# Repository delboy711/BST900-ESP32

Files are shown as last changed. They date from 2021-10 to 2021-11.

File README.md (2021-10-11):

# BST900-ESP32
ESP32 firmware to control BST900 Boost Converters remotely
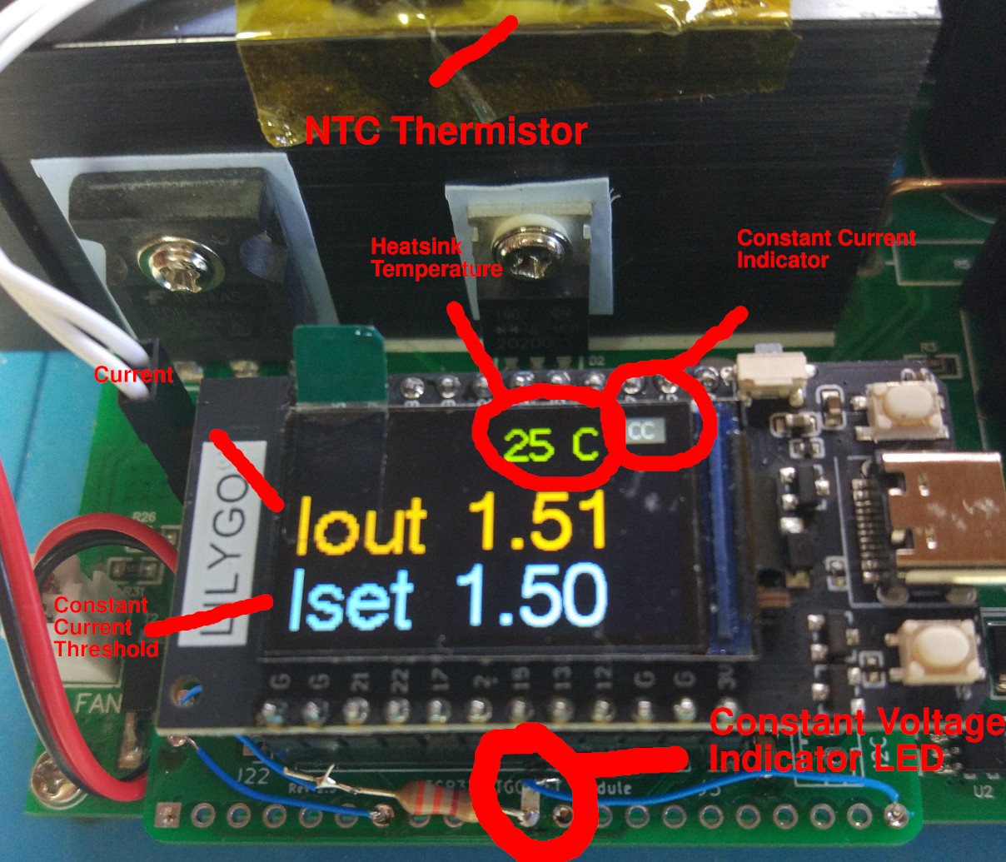
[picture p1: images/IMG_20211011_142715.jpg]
BST900-ESP32

[BST900](aliexpress.com/item/32838432319.html) boost converters are widely and cheaply available on AliExpress. They are sold under the brand name Ming-He among others, and there are also no-name clones available even cheaper.
They are claimed to operate up to 15A and 900W, but personally I would not operate them at that power without improvements to the cooling which I have detailed in my BST900 repository.

## Function
This firmware is offered as an evolution from [BST900](https://github.com/delboy711/BST900) which replaced the stock STM8 firmware and allowed control of a BST900 boost converter over a serial interface.

This new version replaces the BST900 daughter board with an ESP32 with or without an integrated TFT display and allows a BST900 
to be controlled remotely over a WiFi interface using MQTT, and for statistics to be gathered.
On power up the controller will revert to its saved state.

Local control is not currently supported. 

It has been designed to be used with a [TTGO T-Display board](aliexpress.com/item/33050667207.html), but is easily adapted for other display options (or none). An [ADS1115 ADC converter](aliexpress.com/item/32648046830.html) may optionally be used in preference to the onboard ESP32 ADC. The ADS1115 performs considerably better than the on board ADC in ESP32 and is highly recommended.
(All links to stores are examples only.)

In its initial version local control is not possible. If you are looking for a wider set of features, or for management of other types of converters check out 
[Drok-Juntek-on-steroids](https://github.com/rin67630/Drok-Juntek-on-steroids)

## Features

* Control over Voltage and Current over a wireless interface using MQTT.  Many variables may be controlled over MQTT including calibration.
* Statistics and alarms over MQTT
* Temperature measurement and alarms with an NTC thermistor attached to converter heatsink.
* Automatic fan control. Fan speed is proportional to either temperature or load current.
* Closed loop feedback to ensure output Voltage is accurate in Constant Voltage (CV) mode, and Output Current is accurate in Constant Current (CC) mode.
* Choice of display modes showing combinations of Input Voltage, Output Voltage, Output Current, Constant Current (CC) indication, and Temperature.
* Automatic shutdown on over temperature alarm, or on loss of communication with remote controller.
* Saving of all parameters in Flash memory. On power on, the controller will revert to this state.
* Over the Air software updates.

## Application
My home battery system is charged from AC mains. A BST900 Boost Converter is used to boost an AC to DC power supply output up to the battery voltage, and software
 running on NodeRed dynamically controls the constant current limit of the BST900 to match solar panel production to minimise export to the grid and save power for use later in the day.

## Compiling
This code compiles with PlatformIO IDE using the Arduino framework. Refer to the platformio.ini file for required libraries if using Arduino IDE.
Put your WIFI and MQTT credentials in the file include/credentials.h, and your MQTT server address and topic details in include/defines.h

## Usage
The BST900 will listen for commands on one MQTT topic, and send statistics every 30 seconds on another. By default it will time out and restart if no commands are 
received for two minutes. On power on it will send two messages giving its configuration and calibration settings.
Commands and statistics are JSON formatted like for example :-
```{"volts":45000,"amps":8000,"enable":true,"fan":0}```
Keywords may appear in any order. A list of keywords and their data types and ranges is in the file Keywords.md
If the keyword `"save":true` is given, all parameters are saved to flash memory and will be restored on power up.

## Hardware Connections
Connect the TTGO T-Display board to the ESP32 in the following way. BST900 pins are numbered from the top down.

|BST900 Left Socket | Signal Name  | TTGO Pin | ADS1115 Pin | Function |
| --- | --- | --- | --- | --- |
| Pin 1 | Iout Sense | GPIO 38 | Chan 1 | Current sense. Use either ADS115 or ESP32 pins | 
| Pin 2 | Vout Sense | GPIO 39 | Chan 2 | Voltage out sense. |
| Pin 3 | Vin Sense | GPIO 37 | Chan 0 | Voltage in sense. |
| Pin 4 | Iout PWM | GPIO 13 | | Constant Current threshold control |
| Pin 5 | Vout PWM | GPIO 15 | | Voltage out control |
| Pin 6 | Enable | GPIO 13 | | Converter Enable |
| Pin 7 | CV/CC Indicator | GPIO 27 | | Constant Voltage/Constant Current Indicator **Not** 3.3V safe|
| Pin 8 | Fan PWM | GPIO 2 | | Fan speed control |
| | SCL | GPIO 22 | SCL | I2C Clock |
| | SCD | GPIO 21 | SCD | I2C Data |
| | ADC Ref | GPIO 33 | +3.3V | Connect to 3.3V power rail. Used to compare with NTC temp reading |
| | Temp | GPIO 36 | | Connect up as +3.3V--10k resistor--GPIO 36--NTC Thermistor--GND |

Thermistor is [10K nominal at 25deg C Beta Coefficient=3950](https://lcsc.com/product-detail/NTC-Thermistors_Nanjing-Shiheng-Elec-MF52A103J3950-A1_C123378.html) or similar.
**Note:** Pin7 CV/VV is not 3.3V safe. At times 5V may appear on this pin. It must therefore be dropped down before the GPIO27 pin. A convenient method of dropdown is Pin7--3.3K resistor--GPIO27--Blue LED--GND
A blue LED will have ~2.5V forward voltage drop and will ensure a safe voltage appears on GPIO27. 
The LED will also serve as a visible indicator when the BST900 is in Constant Voltage mode.

If using ESP32 ADC connect 100nF capacitors from GPIO Pins 37, 38, and 39 to GND.

| BST900 Right Socket | Signal Name | TTGO Pin | ADS1115 Pin | Function |
| --- | --- | --- | --- | --- |
| Pin 1 | GND (Input)  | GND | GND | Ground | 
| Pin 2 | GND (Input)  | GND | GND | Ground |
| Pin 3 | GND (Output) | | | Do NOT CONNECT Connecting GNDs together disrupts Iout sense |
| Pin 4 | GND (Output) | | | Do NOT CONNECT Connecting GNDs together disrupts Iout sense |
| Pin 5 | +5V | +5V | | 5V Power rail  |
| Pin 6 | +5V | +5V | | 5V Power rail  |
| Pin 7 | | | | Tx pin (not used) |
| Pin 8 | | | | Rx pin (not used) |
| | | +3.3V | Vcc | ADS1115 power |

A 470 uF capacitor should be connected between +5V and GND as well as a 100nF capacitor.

A [circuit diagram](https://github.com/delboy711/BST900-ESP32/blob/main/hardware/BST900-ESP32/BST900-ESP32.pdf) of how to connect a TTGO T-Display to BST900 is in the hardware folder.

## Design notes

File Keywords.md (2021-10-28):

# MQTT Keywords
This is a list of the JSON keywords used in BST900-ESP32

## Command Keywords

| Keyword | Data Type | Range | Comment |
| :---: | :---: | :--- | :--- |
| amps | float | 1-15.0 | Constant current threshold in A |
| debug | boolean | true/false  | Puts extra debug data on serial interface |
| display | integer | 0 to 4 | Contents of TFT display. 0=blank, 1=Voltages, 2=Current, 3=Combined, 4=Cycle between 1 and 2 |
| enable | boolean | true/false  | Enable/disable boost conversion |
| factory | boolean | true/false  | Return to factory defaults and restart |
| fan | integer | 0-255 | Override auto fan speed. 0=auto Fan, 1-255=Fan speed |
| mqtt_timeout | integer | 20-65535 | Restart if no Mqtt commands seen in this many secs |
| overtemp_thresh | integer | 20-255 | Raise alarm and disable converter for 3 mins if this temperature is exceeded |
| restart | boolean | true/false  | Restart controller |
| save | boolean | true/false  | Save all parameters to Flash memory |
| volts | float | 8.0-120.0 | Output Voltage in V |

### Calibration Keywords

| Keyword | Data Type | Comment |
| :---: | :---: | :--- |
| vin_bias | float | Measured Vin bias offset. Normally zero |
| vin_res | float | Measured Vin units per mV |
| vout_bias | float | Measured Vout bias offset. Normally zero |
| vout_res | float | Measured Vout units per mV |
| iout_bias | float | Measured Iout bias offset. Normally zero |
| iout_res | float | Measured Iout units per mV |
| pwm_vout_bias | float | Vout offset. Normally zero |
| pwm_vout_step | float | Steps per mV |

## Response Keywords

| Keyword | Data Type | Range | Comment |
| :---: | :---: | :--- | :--- |
| bl_intensity | integer | 0-1023 | Backlight Intensity |
| display_mode | integer | 0-4 | Contents of TFT display. 0=blank, 1=Voltages, 2=Current, 3=Combined, 4=Cycle between 1 and 2 |
| enable | boolean | true/false  | Converter enable state |
| mqtt_timeout | integer | 20-65535 | Configyred MQTT Timeout |
| overtemp_thresh | integer | 20-255 | Configured over temperature threshold |
| reset_reason | integer | 1-16 | ESP32 [reset reason]( https://github.com/espressif/arduino-esp32/blob/master/libraries/ESP32/examples/ResetReason/ResetReason.ino) |
| targetIout | integer | 1-15000 | Configured Constant Current threshold in mA |
| targetVout | integer | 1-120000 | Configured Output Voltage in mV |
| Vin | integer | 1-120000 | Last measured Vin in mV|
| Vin_smoothed | integer | 1-120000 | Rolling average of Vin |
| Vout | integer | 1-120000 | Last measured Vout in mV|
| Vin_smoothed | integer | 1-120000 | Rolling average of Vout |
| Iout | integer | 1-15000 | Last measured Iout in mA|
| Iout_smoothed | integer | 1-15000 | Rolling average of Iout |
| fan | integer | 0-255 | Current fan voltage |
| overtemp | boolean | true/false  | Temperature alarm state |
| temperature | signedint | -127 to 127 | Current temperature |

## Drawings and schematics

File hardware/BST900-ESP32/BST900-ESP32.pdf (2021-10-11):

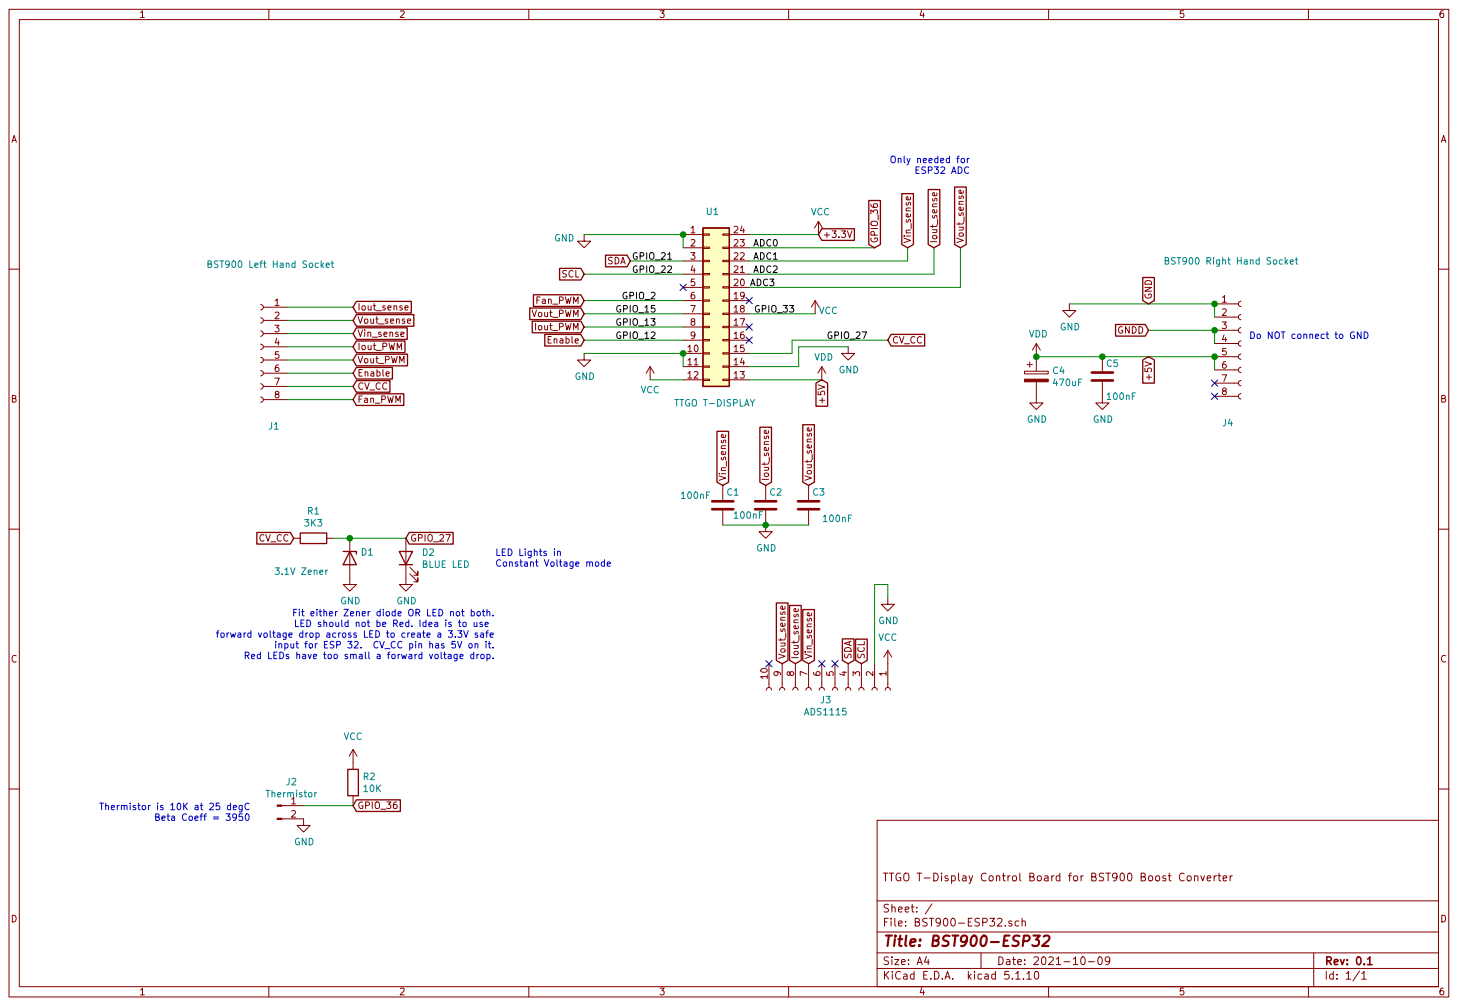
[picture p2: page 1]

Do NOT connect to GND

File: BST900-ESP32.sch Sheet: / TTGO T-Display Control Board for BST900 Boost Converter D2BLUE LED

Fit either Zener diode OR LED not both. LED should not be Red. Idea is to use

forward voltage drop across LED to create a 3.3V safe

input for ESP 32. CV_CC pin has 5V on it.
Red LEDs have too small a forward voltage drop.

Thermistor is 10K at 25 degC

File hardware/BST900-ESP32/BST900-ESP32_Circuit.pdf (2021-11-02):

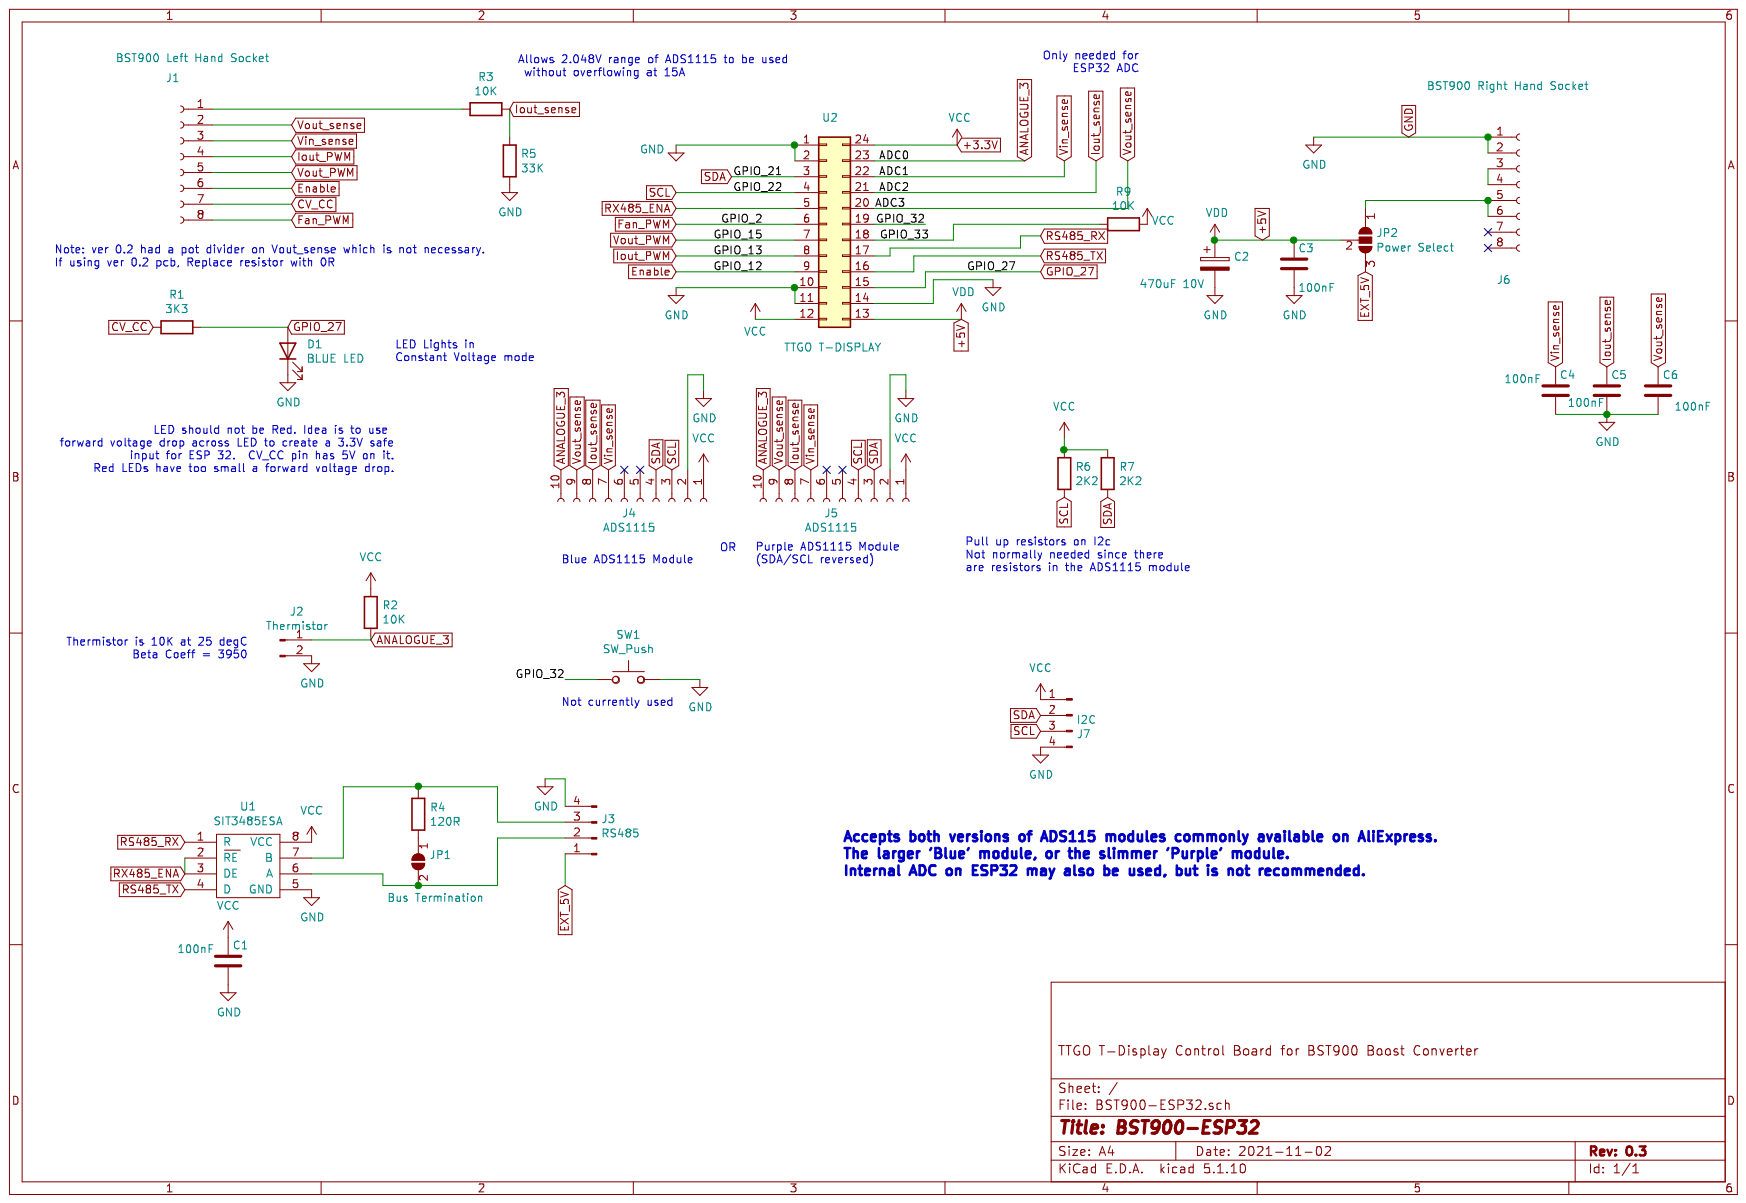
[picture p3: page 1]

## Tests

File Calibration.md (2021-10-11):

# Calibration
The default calibration should be fairly accurate, but if you find you need to recalibrate use this procedure.
Calibration of BST900-ESP32 is relatively easy. Equipment required is a multimeter, and a dummy resistive load
 such as an incandescent light bulb. Also required is a computer running an MQTT server such as [mosquitto](https://mosquitto.org/)
 with a text based MQTT client so commands can be sent to the BST900.
 
 To start calibrating first ensure the BST900 is connected to WiFi. On power on the BST900 will display its IP address on the TFT
  screen for a few seconds. If you do not see this ensure the code has been compiled with the correct credentials in the file 
  inc/credentials.h. Also ensure that credentials.h contains the correct credentials for your MQTT server, and that inc/defines.h contains 
  the IP address of your MQTT server. By default BST900 will subscribe to the topic 'bst900' to receive commands, and will send
   statistics every 30 seconds on the topic 'emon/bst900'.  Be aware that by default BST900 will expect to see a command at least every 
    two minutes on the 'bst900' topic or else it will declare a communication alarm and restart itself. This timeout period can 
    be adjusted by sending a JSON formatted MQTT command in the format.
    ```{"mqtt_timeout":600}```
If using mosquitto as an MQTT client the command would look like this:-
```mosquitto_pub  -u 'mqttuser' -P 'mqttpassword' -t 'bst900' -m '{"mqtt_timeout":600}'```

## Calibrating Voltage readings
 With a stable power supply of at least 9V connected to the BST900, and the output terminals of the BST900
  left open circuit open a terminal window and subscribe to the topic BST900 is sending statistics on.
  ```mosquitto_sub -v -u 'mqttuser' -P 'mqttpassword' -t 'emon/bst900'```
  On power up BST900 will send two messages giving the [reset reason](https://github.com/espressif/arduino-esp32/blob/master/libraries/ESP32/examples/ResetReason/ResetReason.ino), setup parameters, and 
  the calibration parameters. All these parameters can be configured with MQTT commands.

### Calibrating Measuring Input Voltage
  With a multimeter attached to the input terminals compare the measered voltage with the reported Voltage 'Vin' in the statistics report.
  Adjust the parameter 'vin_res' until the reported Voltage matches the measured using MQTT commands in the format.
  ```mosquitto_pub  -u 'mqttuser' -P 'mqttpassword' -t 'bst900' -m '{"vin_res":34.335}'```
  Now repeat the procedure using a much higher input voltage.
  Note: If you cannot find a value for 'vin_res' which works across all voltage ranges it is possible (but not likely) that adjusting the 
  parameter 'vin_bias' may help.
  
### Calibrating Measuring Output Voltage
  Now move the multmeter to the output terminals of the BST900. By definition the input voltage of a boost converter will appear on the output terminals even when it is not enabled.
  Repeat the previous procedure this time adjusting the parameter 'vout_res'.
  
### Calibrating Measuring Output Current
  Next with output terminals still open circuit look at the reported statistic for Iout and adjust the parameter 'iout_bias' until the reported current is zero.
  Now attach your dummy load to the output terminals. With your multimeter measure the current flowing in the dummy load.
  Compare with the reported value of Iout and adjust the parameter 'iout_res' until they match.  Repeat with another dummy load drawing a different current.

### Calibrating Output Voltage
  Calibration of output Voltage is semi automatic. So long as the parameter 'pwm_vout_step' is roughly accurate, then the BST900 will
   automatically adjust the output voltage until the measured output voltage matches the target voltage. If you find the output voltage
    is not accurate it may be adjusted by the parameter 'pwm_vout_step'. (Make small changes only).
    
  To set output voltages use the command:-
  ```mosquitto_pub  -u 'mqttuser' -P 'mqttpassword' -t 'bst900' -m '{"volts":3500, "enable":true}'```
  Note: Voltage is expressed in milliVolts, and current is expressed in milliAmps as integer numbers. Enable is a boolean and is either 
  'true' or 'false'.
  Note: Changes to 'pwm_vout_step' will not take effect unless the output voltage is also changed.
  Note: Output voltage will drop if the converter is in 'constant current' mode. Ensure the constant current threshold is high enough when
   calibrating output voltage.
  
### Calibrating Output Constant Current Threshold.
  Calibration of the constant current threshold is fully automatic.
  So long as the measured Iout is accurate then the constant current threshold should also be accurate.
  The command to set a constant current threshold would look like :-
  
  ```mosquitto_pub  -u 'mqttuser' -P 'mqttpassword' -t 'bst900' -m '{"volts":3500, "amps":1200 "enable":true}'```

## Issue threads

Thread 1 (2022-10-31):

BST 900 original firmware  i d like to contribute.

ouinouin, 2022-10-31:
Hi, sorry to bother you on here this project, i m actually just starting to use your "original" BST 900 firmware  in a solar powered environment.
unfortunately there is no "issue" button on the original BST 900 firmware

i prefered the BST900 firmware since it looks easy to manipulate everything i need with the serial port (i can connect an esp32 through the serial port directly and dont need hardware change. ( a great thing would be to be able to get some tasmota interaction on ESP32 :-) .

for now i m noticing while playing with the voltage that the protocol.md might be wrong :

Voltage Set

    Send: "VOLTAGE XXXXX"
    Receive: "VOLTAGE - OK" or "OK"

Set the maximum voltage level in mV.
Use the "CONFIG" command to confirm.

tell me if you re motivated to open the "issue" tab on the bst 900 if i can give feedback (on docs most likely, i m not really a coder).

PS : my project is to connect the input of BST 900 on the 48V DC of my solar powered system, and to dump the extra load in one resistance of my water heater, with a retroaction loop : trying to adapt the dump load dynamically based consumption information received from the solar panel production system, letting some predefined amount flowing in the battery for example, and adapting to the power curve of the sun during the day (i did the same in AC with thyristors, but its highly power inefficient, and i like the idea of doing DC only.
with some other solar enthusiasts, we have plenty of other projects that could take benefit of your great efforts.

delboy711, 2022-11-01:
Hi
Thanks for taking an interest in my project. I have taken a look at the github settings, but because the original BST900 STM8 based project is a fork of another project github does not permit the 'Issues' Tab to be enabled. Feel free to highlight any issues relating to it here.

Now as for the documentation for setting the voltage I have taken a look through the code and it looks to me as if voltage is declared in milliVolts on the serial interface but internally it is converted to centiVolts (because BST900 can have output voltages exceeding 65535mV which would overflow a 16 bit integer)

However it is a long time since I have worked on this code, and I no longer use this version myself so I could be wrong.

Have you got the code working yet? The biggest difficulty with this project is the fact that once you overwrite the stock firmware on the top board there is no way to go back to stock firmware again.

Now regarding your application be aware that a Boost converter like BST900 can raise the output voltage above the input voltage, and can control the current while doing so, but it cannot prevent the input voltage appearing on the output terminals even when disabled.  If you look at the basic circuit diagram of a boost converter you will see the input connects directly to the coil, through a diode to the output terminals. So if you have 48V going in, then the output will always be at least 48V and current can only be controlled when the output is higher than 48V.

I do actually have another project to do a similar function to your application which I use to dump excess solar power into a storage heater.  It uses an esp8266 to switch a Triac on for  complete AC cycles.  It is more efficient than a Thyristor, and does not produce any emf noise.  I have not uploaded this project to Github but if you are interested I could do so.

regards  Derek

ouinouin, 2022-11-02:
@delboy711  thanks for your constructive answer,  well noted for the issue propagation mode of github.
as you said, i could not turn on or off the output of the supply as expected since there is always at least the input voltage on the output.
the code works, i could in a test regulate voltage and current, this rocks. just the buttons seems not working but i dont know if its because i once misconnected the board upside down or because of some code (and i dont need the buttons indeed).

as a note for people interrested in doing the modding, I had to unsolder the 20 pins microcontroller on the board and put a real STM8 from a dev board inplace by unsoldering with hot air becuase i couldnt flash in situ
then I soldered back on the eval board the chinese component, and i still couldnt flash it : meaning, they dont ship this kind of supplies anymore with stm8. but this might be one pin compatible, so frankensteinisation si still doable.

for info , with this boost the goal can also be to supply some loads wich have 110/220AC adapters but in fact have a rectifier (like laptop supplies, led supplies etc etc. i did some interresting tests, some old dell laptop supplies are working directly with the 120V DC ,some led bulbs also works. this could make a lot of sense for a whole DC house transition.

another info : at 52V (which is the average voltage of my dc circuit , I can get a maximum of 300W of power @120V DC output.
I d like to trace the full curve of this unit since they state 15 ampx max and 120V max but there is nowhere a real set of curves of the unit and his efficiency (while doing my next session around this unit in 4 5 weeks, i ll try to caracterize this.

I dlike to have a DC boost unit capable of going from 50V zone to 220 V DC around 1KW ... to be able to try a maximum of devices and make a list of thigs that coud transition direct from ac to DC.  IF you know some macgic chinese stuff able to do this.

for your triac project, yes  id be interrested in seing what you did with a triac, to sse how you could manage to not have the full power during one period.

I have another project in parallel to regulate a dump load with an autotransformer that I would drive with a stepper motor. (nothing ne under the sun , already some projects are there n the internet, just the purpose to regulate and do a dump load is a bit new.)

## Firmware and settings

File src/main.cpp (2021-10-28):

/****************************************
 * BST900-ESP32
 * ESP32 firmware for BST900 BoostConverters
 * 
 * Oct '21
 * Derek Jennings
 * 
 * ****************************************/


#include <Arduino.h>
#include <WiFi.h>
#include <esp_wifi.h>
#include <ESPmDNS.h>
#include <ArduinoOTA.h>
#include <rom/rtc.h>
#include "settings.h"


#include "defines.h"
#include "credentials.h"

#include "adc.h"
#include "mqtt.h"
#include "tft.h"

unsigned long wifi_check = 0;
IPAddress ip;


Mystate state;        //Global structure holding controller state
Mysettings settings;      //Global structure holding target voltage/current

TaskHandle_t Fan_Task = NULL;            //RTOS task handle for Fan management
TaskHandle_t Debug_Task = NULL;

void Debug_Task_function( void * parameter) {
  ulTaskNotifyTake(pdTRUE, portMAX_DELAY);     //Wait until wake up

  for(;;) {
    ulTaskNotifyTake(pdTRUE, pdMS_TO_TICKS(5000));     //Wait 5 secs between reports

    Serial.print("Vin_sample= "); Serial.print(state.adc_chan[0].sample); Serial.print(" Vin= "); Serial.print(state.Vin);
    Serial.print(" Vout_sample= ");  Serial.print(state.adc_chan[2].sample); Serial.print(" Vout= "); Serial.print(state.Vout);
    Serial.print(" Iout_sample= ");  Serial.print(state.adc_chan[1].sample); Serial.print(" Iout= "); Serial.println(state.Iout);  
    Serial.print("Loop time = "); Serial.print((float)state.adc_time/1000.0); Serial.println(" mS");  
  }

}


//Get ESP32 ADC sample
  float readADC(uint8_t adc_pin) {
	uint16_t sum = 0;
	for(int i=0; i< 4; i++) {
		sum += analogReadMilliVolts(adc_pin);
		delay(20);
	}
	sum += analogRead(adc_pin);
	return ((1. * sum) / 5);
}

//Steinhart-Hart Equation to get Temperature from an NTC
// See https://arduinodiy.wordpress.com/2015/11/10/measuring-temperature-with-ntc-the-steinhart-hart-formula/
float ntc_temp(float vref  ) {    //vref= power rail sample, series = series resistor
  
  float adc_sample = readADC(TEMP);               //Get sample of V across NTC
  Serial.print("Sample = "); Serial.print(adc_sample); Serial.print("  Vref= "); Serial.println(vref);
  float Resistance = (vref / adc_sample) - 1.0;
  Resistance = SERIES / Resistance;
  Serial.print(Resistance); Serial.println(" Ohm");
  float steinhart;
  steinhart = Resistance / NOMINAL; // (R/Ro)
  steinhart = log(steinhart); // ln(R/Ro)
  steinhart /= BETA; // 1/B * ln(R/Ro)
  steinhart += 1.0 / (25 + 273.15); // + (1/To)
  steinhart = 1.0 / steinhart; // Invert
  steinhart -= 273.15; // convert to C

  //Serial.print("Temperature ");
  //Serial.print(steinhart);
  //Serial.println(" oC");

  return steinhart;
}

void Fan_Task_function( void * parameter) {
  ledcSetup(14, 25, 8);                     // Create 8 bit resolution@ 25Hz  PWM for Fan
  ledcAttachPin(FAN_PIN, 14);               //Attach PWM channel to fan pin
  float vref_sample = readADC(ADC_VREF);    //Measure 3.3V rail voltage as a reference
  unsigned long overtemp_timer=millis();

  for(;;) {

    ulTaskNotifyTake(pdTRUE, pdMS_TO_TICKS(3000));     //Wait 3 secs for wake up and then proceed


#ifdef TEMP       //Temperature controlled fan
    state.temperature = round(ntc_temp(vref_sample));
    if (state.temperature > settings.overtemp_thresh) {    //Temperature too high!!!
      state.overtemperature = true;  //Raise alarm
      digitalWrite(ENA_PIN, 0);     //Disable Controller NOTE: ENA pin does not actually work in BST900 so adc routine has to test if alarm state and disable PWM signal
      overtemp_timer = millis();    //Make note of time
    } else {
      if(state.overtemperature) {   //Still in alarm state
        unsigned long time_now = millis();
        if( time_now - overtemp_timer > OVERTEMP_TIMEOUT) {   //Timer has expired OK to reenable
          if(settings.enable) digitalWrite(ENA_PIN, 1);     //Enable Controller
          state.overtemperature = false;
        }
      }
    }
    //state.fan_pwm = constrain(map(state.temperature, 28, 50, FAN_MIN, 255), 0, 255);
    float temp_fan = ((float)state.temperature - FAN_TEMP_MIN) * (255.0 - FAN_MIN) / (FAN_TEMP_MAX - FAN_TEMP_MIN) + FAN_MIN;   //map temp range to fan range
    if ( temp_fan < FAN_MIN ) state.fan_pwm =0;
    else if ( temp_fan > 255.0 ) state.fan_pwm =255;
    else state.fan_pwm = (uint8_t)temp_fan;
#else                   //Fan speed dependent on current
    state.fan_pwm = constrain(map(state.Iout, 2500, 9000, FAN_MIN, 255), 0, 255);
    if(state.Iout < 2000) state.fan_pwm = 0;
#endif
    if(state.fan_pwm < FAN_MIN) state.fan_pwm = 0;   //Too low to start fan
    if (settings.fan == 0) {
      ledcWrite(14, state.fan_pwm );
  } else ledcWrite(14, settings.fan);   //Set Fan override speed
  }
}

void SetupOTA() {
  ArduinoOTA.onStart([]() { String type;
    if (ArduinoOTA.getCommand() == U_FLASH)
      type = "sketch";
      else
      type = "filesystem";
      ESP_LOGI(TAG, "Start updating %s", type);
  });
  ArduinoOTA.onEnd([]() { ESP_LOGD(TAG, "\nEnd"); });
  ArduinoOTA.onProgress([](unsigned int progress, unsigned int total)
                        { ESP_LOGD(TAG, "Progress: %u%%\r", (progress / (total / 100))); });
  ArduinoOTA.onError([](ota_error_t error) {
    ESP_LOGD(TAG, "Error [%u]: ", error);
    if (error == OTA_AUTH_ERROR) ESP_LOGE(TAG, "Auth Failed");
    else if (error == OTA_BEGIN_ERROR) ESP_LOGE(TAG, "Begin Failed");
    else if (error == OTA_CONNECT_ERROR) ESP_LOGE(TAG, "Connect Failed");
    else if (error == OTA_RECEIVE_ERROR) ESP_LOGE(TAG, "Receive Failed");
    else if (error == OTA_END_ERROR) ESP_LOGE(TAG, "End Failed");
    });

  ArduinoOTA.setHostname(HOSTNAME);
  ArduinoOTA.setMdnsEnabled(true);
  ArduinoOTA.begin();
}


void Wifi_Connect() {
  wl_status_t status = WiFi.status();
  if (status == WL_CONNECTED) return;
  WiFi.mode(WIFI_STA);
  WiFi.setHostname(HOSTNAME);
  Serial.print("Connecting to WiFi");
  WiFi.begin(WIFI_SSID, WIFI_PASSWORD);
}


void onWifiConnect(WiFiEvent_t event, WiFiEventInfo_t info)
{
  Serial.print("Got IP address:  ");
  ip = WiFi.localIP();
  Serial.println(WiFi.localIP().toString());
  Mqtt_Connect();       //Connect Mqtt Client if not already working
  MDNS.begin(HOSTNAME);
  xTaskNotify(Tft_Task, 0x00, eNotifyAction::eNoAction);
  SetupOTA();           //Setup ESP32 OTA Updates
}

void onWifiDisconnect(WiFiEvent_t event, WiFiEventInfo_t info)
{

  Wifi_Connect();   //Reconnect

}


void setup() {

  Serial.begin(115200);
  delay(1000);
  state.reset_reason = rtc_get_reset_reason(0);
  Serial.print("Reset Reason = "); Serial.println(state.reset_reason);

//Restore Configuration from Flash
  Mysettings testsettings;
  if (Settings::ReadConfigFromPreferences((char *)&testsettings, sizeof(testsettings))) {  //Test if config is good before loading into running config
    Settings::ReadConfigFromPreferences((char *)&settings, sizeof(settings));
    Serial.println("Configuration OK");
  } else {
    Settings::PreferencesFactoryDefault();
    Settings::WriteConfigToPreferences((char *)&settings, sizeof(settings));    //Write default config
  }
  
  xTaskCreatePinnedToCore( ADC_Task_function,  "ADC_Task",  2048,  NULL,  4,   &ADC_Task, 1);  //This is the task to read the ADC
  xTaskCreatePinnedToCore( Mqtt_Task_function,  "Mqtt_Task",  4096,  NULL,  3,   &Mqtt_Task, 1);  //This is the task to handle MQTT commands
  xTaskCreatePinnedToCore( Fan_Task_function,  "Fan_Task",  1024,  NULL,  5,   &Fan_Task, 1);  //This is the task to handle the Fan
  xTaskCreatePinnedToCore( Tft_Task_function,  "Tft_Task",  4096,  NULL,  2,   &Tft_Task, 1);  //This is the task to handle TFT display
  xTaskCreatePinnedToCore( Debug_Task_function,  "Debug_Task",  2048,  NULL,  4,   &Debug_Task, 1);  //This is the task to output Debug messages

  //LoadConfig();
  WiFi.onEvent(onWifiConnect, system_event_id_t::SYSTEM_EVENT_STA_GOT_IP);
  WiFi.onEvent(onWifiDisconnect, system_event_id_t::SYSTEM_EVENT_STA_DISCONNECTED);

  Wifi_Connect();
  
  state.mqtt_active = millis();     //Prime MQTT activity timer
}

void loop() {
  ArduinoOTA.handle();
  
  unsigned long millis_now = millis();
  if( millis_now - wifi_check > WIFI_TIMEOUT ) {  //Every 30 secs ensure we are connected to Wifi
    Wifi_Connect();                               //Does nothing if already connected
    Serial.println("Still Connected");
    wifi_check = millis_now;
  }
  if(millis_now - state.mqtt_active > settings.mqtt_timeout && settings.mqtt_timeout > 0) {  //Check we still have contact with MQTT
    Serial.println("PANIC!! Lost contact with MQTT Control. Rebooting");
    delay(3000);
    ESP.restart();
  }

  delay(100);
  yield();
}

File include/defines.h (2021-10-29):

#ifndef defines_H_
#define defines_H_

#pragma once

#include <Arduino.h>
#include <ADS1115_WE.h>

#define HOSTNAME "BST900"               //Set hostname for mDNS
#define MQTT_RX_TOPIC "bst900"          //Topic to listen on for commands
#define MQTT_TX_TOPIC "emon/bst900"     //Topic to send status messages to

#define VIN_MAX      60
#define VOUT_MAX     120
#define IOUT_MAX     15
#define FAN_MIN      90.0                 //Minimum PWM required to start Fan as a float
#define FAN_TEMP_MIN 28.0                 //Temp fan starts at
#define FAN_TEMP_MAX 50.0                 //Temp fan is at full speed


/**********************************************
 * ADC Setup
 * Either internal ESP32 or external ADS1115 ADC
 * May be used
 * 
 * ********************************************/

#define HAS_ADS1115                         //Uses ADS1115 ADC converter instead of ESP32 internal ADC

#ifdef HAS_ADS1115                            //Uses ADS1115 ADC converter instead of ESP32 internal ADC
// THESE PARAMETERS FOR ADS1115 ADC	
#define Vin_BIAS   	    0.0	    //TBD               ADS1115
#define Vin_RES   	    34.517   //Was 34.335	//Provisional        ADS1115
	
#define Vout_BIAS		0.0     //TBD               ADS1115
#define Vout_RES 		67.599  // was 67.894	// Provisional      ADS1115

#define Iout_BIAS		48      // was 41.0	// Provisional      ADS1115
#define Iout_RES 		5.250   // was 5.065	// TBD              ADS1115

#define ADS_Ch2_Range ADS1115_RANGE_2048
#define ADS_Ch1_Range ADS1115_RANGE_2048
#define ADS_Ch0_Range ADS1115_RANGE_2048

#define Vin_PIN   ADS1115_COMP_0_GND        //ADS1115 Channel0
#define Iout_PIN  ADS1115_COMP_1_GND        //ADS1115 channel1
#define Vout_PIN  ADS1115_COMP_2_GND        //ADS1115 Channel2

#else   //HAS_ADS1115                       //Uses ESP32 internal ADC
// THESE PARAMETERS FOR ESP32 ADC	
#define Vin_BIAS   	    0.0	     //TBD              ESP32
#define Vin_RES   	    34.335	 //TBD              ESP32
	
#define Vout_BIAS		0       //TBD               ESP32
#define Vout_RES 		67.894	// TBD              ESP32

#define Iout_BIAS		41.0	// Provisional      ESP32
#define Iout_RES 		5.065	// TBD              ESP32


#define Vin_PIN   37            //Vin               ESP32
#define Iout_PIN  38            //Iout              ESP32
#define Vout_PIN  39            //Vout              ESP32
#endif  //HAS_ADS1115

	
//#define PWM_Iout_BIAS	0.0		//
//#define PWM_Iout_STEP	0.0511	//TBD
#define PWM_Vout_BIAS	0.0		 //
#define PWM_Vout_STEP	0.0363	     //Provisional

#define I2C_SCL     22          // GPIO5 for I2C (Wire) System Clock
#define I2C_SDA     21          // GPIO4 for I2C (Wire) System Data
#define TFT_BL       4          // Display backlight control pin

#define BUTTON_UP    35         //not currently used
#define BUTTON_DOWN  0          //not currently used

/***********************************
 * NTC Thermistor variables
 * *********************************/
#define TEMP        36          //GPIO Pin to measure NTC temperature  Uncomment if not used
#define ADC_VREF    33          //ADC PIN to measure 3.3V rail to compare with NTC
#define SERIES      10000.0     //Series resistor in line with NTC  3.3V---SERIES---ADC---NTC----GND
#define NOMINAL     10000.0     //Nominal NTC resistance
#define BETA        3950.0      //Beta Coefficient of NTC from spec sheet
#define OVERTEMP    60          //Over temp threshold shutdown
#define OVERTEMP_TIMEOUT 180    //Number of secs after overtemp condition clears before re- enabling


/************************************
 * Hardware connections
 * **********************************/

#define PWM_V       15  // Pin GPIO15  (Vpwm)
#define PWM_I       13  // Pin GPIO13  (Ipwm)
#define ENA_PIN     12  // Enable pin
#define FAN_PIN     2
#define CC_CV_PIN   27

#define WIFI_TIMEOUT 30000   //Interval between checking for WiFi
#define MQTT_TIMEOUT 120   //Panic if no MQTT messages received in this time in secs Set to 0 to disable (minimum 20 secs)


/***************************************
 * Data Structures
 * *************************************/
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

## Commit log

2021-10-11 Initial upload
    [BST900-ESP32.kicad_pcb, BST900-ESP32.sch]
2021-10-27 Set Fan PWM to 25Hz
2021-10-27 Fix 'enable' operation, and Vin measurement
    [adc.cpp, defines.h, mqtt.cpp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]
2021-10-29 Tune ADC algorithm and default calibration
2021-11-02 New PCB Hardware
    [BST900-ESP32-B_Cu.gbr, BST900-ESP32-B_Mask.gbr, BST900-ESP32-B_Paste.gbr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]
